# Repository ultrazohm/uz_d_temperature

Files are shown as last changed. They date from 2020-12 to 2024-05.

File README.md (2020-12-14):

# README #

### Ultrazom Temperature Measurement Card ###
This digital sensor card allows the Ultrazohm to measure up to 60 multisensor temperature Channel, of which 40 can be accessed directly on the front panel of the Ultrazohm.
This card is still in development, so please be carefull if you create your own Version of this card!

### Actual Points on the ToDo list ###

* Write some documentation and how-to's
* fix wiring between SPI busses and Connector. Connections made in PCB, buggy in schematic?

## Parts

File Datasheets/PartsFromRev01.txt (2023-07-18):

DC/DC : ROE-2405S 5V 200mA
 https://www.mouser.de/ProductDetail/RECOM-Power/ROE-2405S?qs=wlO1EFRhkBD1PQdCwpEhnw%3D%3D
ADUM : ADUM 4150 ARIZ
https://www.analog.com/en/products/adum4150.html#product-overview

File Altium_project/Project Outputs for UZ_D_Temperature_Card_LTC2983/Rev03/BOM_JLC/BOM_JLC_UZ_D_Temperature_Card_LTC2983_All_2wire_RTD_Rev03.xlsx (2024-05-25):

Comment | Designator | Footprint | LCSC Part Number | Manufacturer Part Number
0.1 µF | C1A, C1B, C1C, C5A, C5B, C5C, C6A, C6B, C6C, C10A, C10B, C10C, C11A, C11B, C11C, C12A, C12B, C12C, C14A, C14B, C14C, C15A, C15B, C15C, C16A, C16B, C16C, C17A, C17B, C17C, C18A, C18B, C18C, C19A, C19B, C19C, C20A, C20B, C20C, C21A, C21B, C21C, C22A, C22B, C22C, C23A, C23B, C23C, C24A, C24B, C24C, C25A, C25B, C25C, C26A, C26B, C26C, C27A, C27B, C27C, C28A, C28B, C28C, C29A, C29B, C29C, C30A, C30B, C30C, C31A, C31B, C31C, C32A, C32B, C32C, C33A, C33B, C33C, C35 | C_0603 | C14663 | C0603X104K5RAC7411
10 µF | C2A, C2B, C2C, C3A, C3B, C3C, C4A, C4B, C4C, C7A, C7B, C7C, C8A, C8B, C8C, C9A, C9B, C9C, C13A, C13B, C13C, C34, C36 | C_0603 | C19702 | GRM185R60J106ME15D
100 nF | C37 | C_0603 | C14663 | C0603C104K9PACTU
150060GS84000 | D1A, D1B, D1C, D2 | WL-SMCW_0603 | C72043 | 150060GS84000
0154.500DR | F1 | Littlefuse_154 | C720204 | 0154.500DR
10k | R1A, R1B, R1C | RES 0603_1608 | C25804 | RK73B1JTTD103J
680R | R2A, R2B, R2C, R69 | RES 0603_1608 | C23228 | RK73B1JTTDD681J
0R | R3A, R3B, R3C, R4A, R4B, R4C, R5A, R5B, R5C, R6A, R6B, R6C, R7A, R7B, R7C, R8A, R8B, R8C, R9A, R9B, R9C, R10A, R10B, R10C, R11A, R11B, R11C, R12A, R12B, R12C, R13A, R13B, R13C, R14A, R14B, R14C, R15A, R15B, R15C, R16A, R16B, R16C, R17A, R17B, R17C, R18A, R18B, R18C, R19A, R19B, R19C, R20A, R20B, R20C, R21A, R21B, R21C, R22A, R22B, R22C, R23A, R23B, R23C, R25A, R25B, R25C, R26A, R26B, R26C, R28A, R28B, R28C, R30A, R30B, R30C, R32A, R32B, R32C, R34A, R34B, R34C, R36A, R36B, R36C, R38A, R38B, R38C, R40A, R40B, R40C, R42A, R42B, R42C, R48, R50, R51, R52, R53, R54, R56, R57, R58, R59, R60, R62, R63, R64, R65, R66, R68, R70 | RES 0603_1608 | C21189 | RC0603JR-070RL
1k | R24A, R24B, R24C | RES 0603_1608 | C21190 | 0603WAF1001T5E
R_TF | R49 | RESC1608X55X30NL15T15 | C21189
4k7 | R71, R72, R73 | RES 0603_1608 | C23162 | 0603WAF4701T5E
100k | R75, R76 | RES 0603_1608 | C25803 | RK73B1JTTD104J
M24C02-WMN6TP | U1 | D0008A_N | C7562 | M24C02-WMN6TP
ADUM4150 | U2A, U2B, U2C | SOIC-20-ADUM4150 | C660948
DC/DC_24_5 | U3A, U3B, U3C | SIP4DCDC | C970824
LTC2983 | U4A, U4B, U4C | 48_LGFP(7x7) | C427448
DC/DC_24_3V3 | U5 | SIP4DCDC | C7500913
IPL1-115-01-L-D-RA-K | X1A, X1C | IPL1-115-01-XX-D-RA | C7423882 | IPL1-115-01-L-D-RA-K

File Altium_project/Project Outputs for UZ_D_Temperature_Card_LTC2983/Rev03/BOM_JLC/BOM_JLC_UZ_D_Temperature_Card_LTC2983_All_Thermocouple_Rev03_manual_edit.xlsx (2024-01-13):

Comment | Designator | Footprint | LCSC Part Number | Alternative
0.1 µF | C1A, C1B, C1C, C5A, C5B, C5C, C6A, C6B, C6C, C10A, C10B, C10C, C11A, C11B, C11C, C12A, C12B, C12C, C14A, C14B, C14C, C15A, C15B, C15C, C16A, C16B, C16C, C17A, C17B, C17C, C18A, C18B, C18C, C19A, C19B, C19C, C20A, C20B, C20C, C21A, C21B, C21C, C22A, C22B, C22C, C23A, C23B, C23C, C24A, C24B, C24C, C25A, C25B, C25C, C26A, C26B, C26C, C27A, C27B, C27C, C28A, C28B, C28C, C29A, C29B, C29C, C30A, C30B, C30C, C31A, C31B, C31C, C32A, C32B, C32C, C33A, C33B, C33C, C35 | C_0603 | C2803384
10 µF | C2A, C2B, C2C, C3A, C3B, C3C, C4A, C4B, C4C, C7A, C7B, C7C, C8A, C8B, C8C, C9A, C9B, C9C, C13A, C13B, C13C, C34, C36 | C_0603 | C5240381
100 nF | C37 | C_0603 | C2803384
150060GS84000 | D1A, D1B, D1C, D2 | WL-SMCW_0603 | C72043
0154.500DR | F1 | Littlefuse_154 | C720204
10k | R1A, R1B, R1C | RES 0603_1608 | C25804
680R | R2A, R2B, R2C, R69 | RES 0603_1608 | C23228
0R | R3A, R3B, R3C, R4A, R4B, R4C, R5A, R5B, R5C, R6A, R6B, R6C, R7A, R7B, R7C, R48, R50, R51, R52, R53, R54, R56, R57, R58, R59, R60, R62, R63, R64, R65, R66, R68, R70 | RES 0603_1608 | C21189
1k | R8A, R8B, R8C, R9A, R9B, R9C, R10A, R10B, R10C, R11A, R11B, R11C, R12A, R12B, R12C, R13A, R13B, R13C, R14A, R14B, R14C, R15A, R15B, R15C, R16A, R16B, R16C, R17A, R17B, R17C, R18A, R18B, R18C, R19A, R19B, R19C, R20A, R20B, R20C, R21A, R21B, R21C, R22A, R22B, R22C, R23A, R23B, R23C | RES 0603_1608 | C21190
R_TF | R49 | RESC1608X55X30NL15T15 | C21189
4k7 | R71, R72, R73 | RES 0603_1608 | C23162
100k | R75, R76 | RES 0603_1608 | C25803
M24C02-WMN6TP | U1 | D0008A_N | C7562
ADUM4150 | U2A, U2B, U2C | SOIC-20-ADUM4150 | C660948
DC/DC_24_5 | U3A, U3B, U3C | SIP4DCDC | C970824
LTC2983ILX | U4A, U4B, U4C | 48_LGFP(7x7) | C427448
DC/DC_24_3V3 | U5 | SIP4DCDC | C7500913 | C2684906
IPL1-115-01-L-D-RA-K | X1A, X1C | IPL1-115-01-XX-D-RA | C7423882

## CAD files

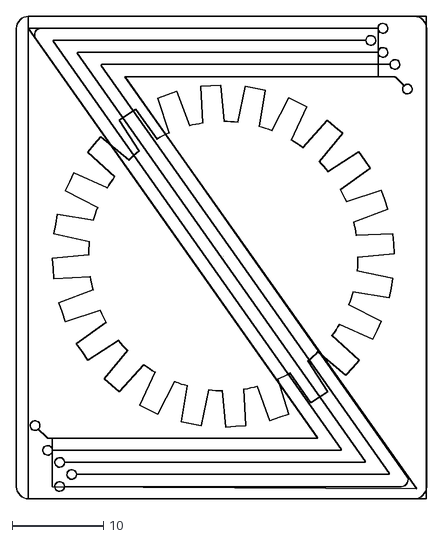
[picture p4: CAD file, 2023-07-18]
logo/V4_fit_mirrored.dxf
45.0 x 52.9

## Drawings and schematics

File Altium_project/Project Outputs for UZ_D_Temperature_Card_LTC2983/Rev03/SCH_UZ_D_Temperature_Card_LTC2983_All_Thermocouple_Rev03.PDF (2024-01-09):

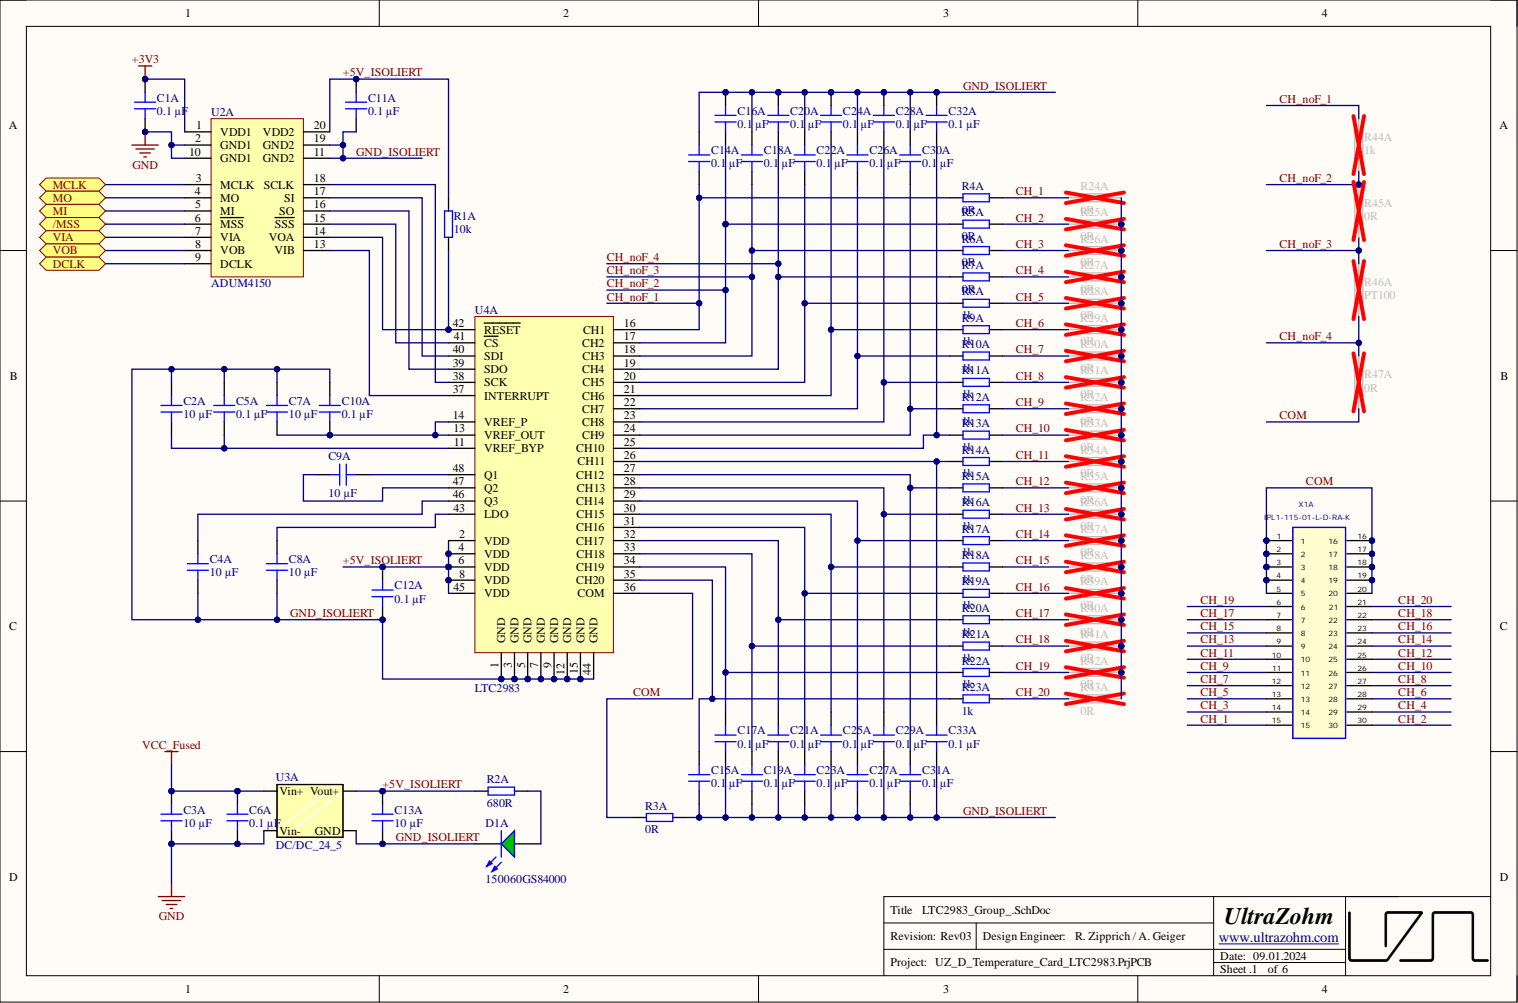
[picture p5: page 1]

1 0 | | 15 SO 16 SI 17 SCLK 18 GND2 19 VDD2 20 4 SSS 1 1

MCL
MI /MSS VIA VOB

1 3

4 | 1 8
3 | 1 9
3 | 2 0

1 3 | | 2 4
1 1 | | 2 5

4 3 | 3 0
2 | 3 1 | 1

G N D _ISO LIE RT

Rev i s n

Dat e :

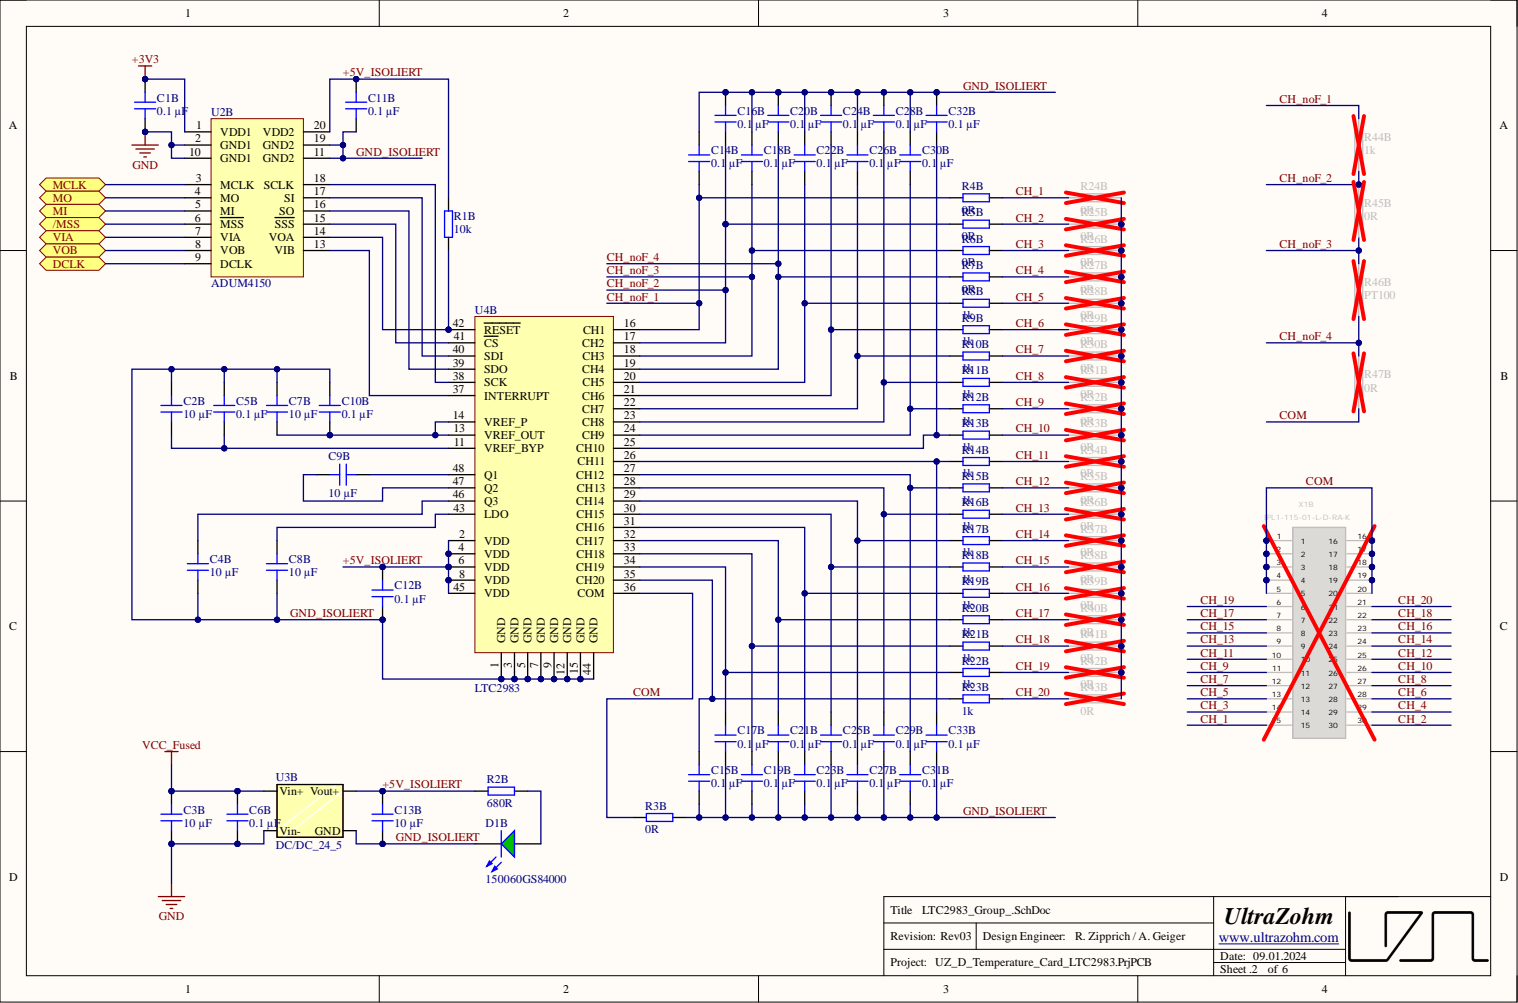
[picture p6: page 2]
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

MCL
MI /MSS VIA VOB

4 | 1 8
3 | 1 9
3 | | 2 0

1 3 | | 2 4
1 1 | | 2 5

4 3 | 3 0
2 | 3 1 | 1

G N D _ISO LIE RT

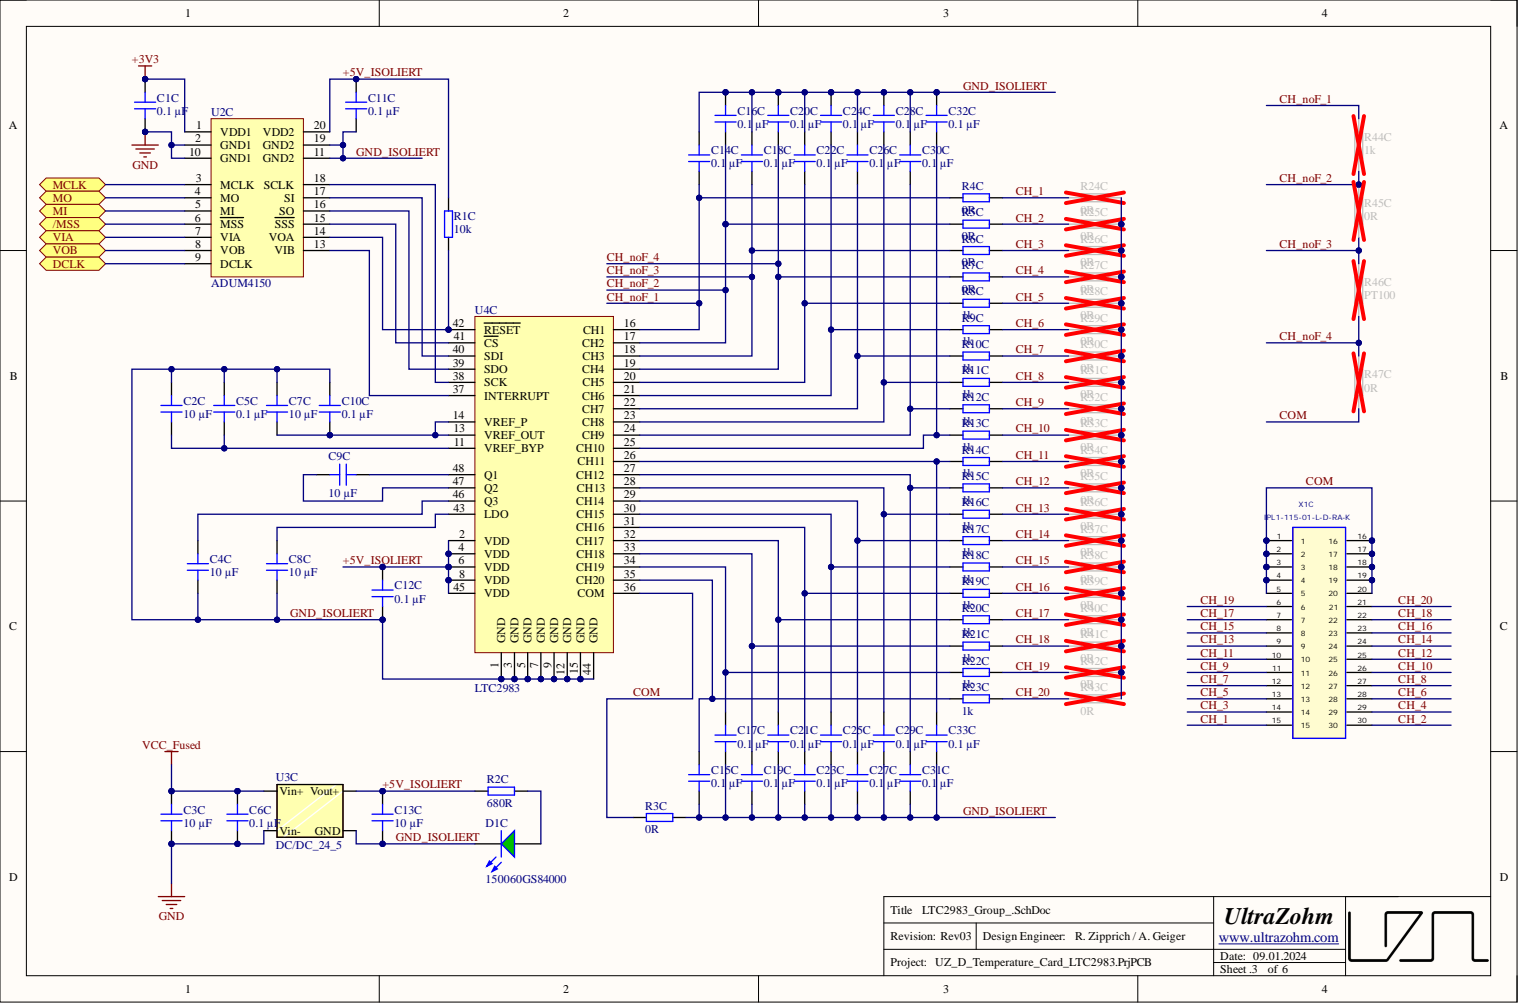
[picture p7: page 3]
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

MCL
MI /MSS VIA VOB

4 | 1 8
3 | 1 9
3 | | 2 0

1 3 | | 2 4
1 1 | | 2 5

4 3 | 3 0
2 | 3 1 | 1

G N D _ISO LIE RT

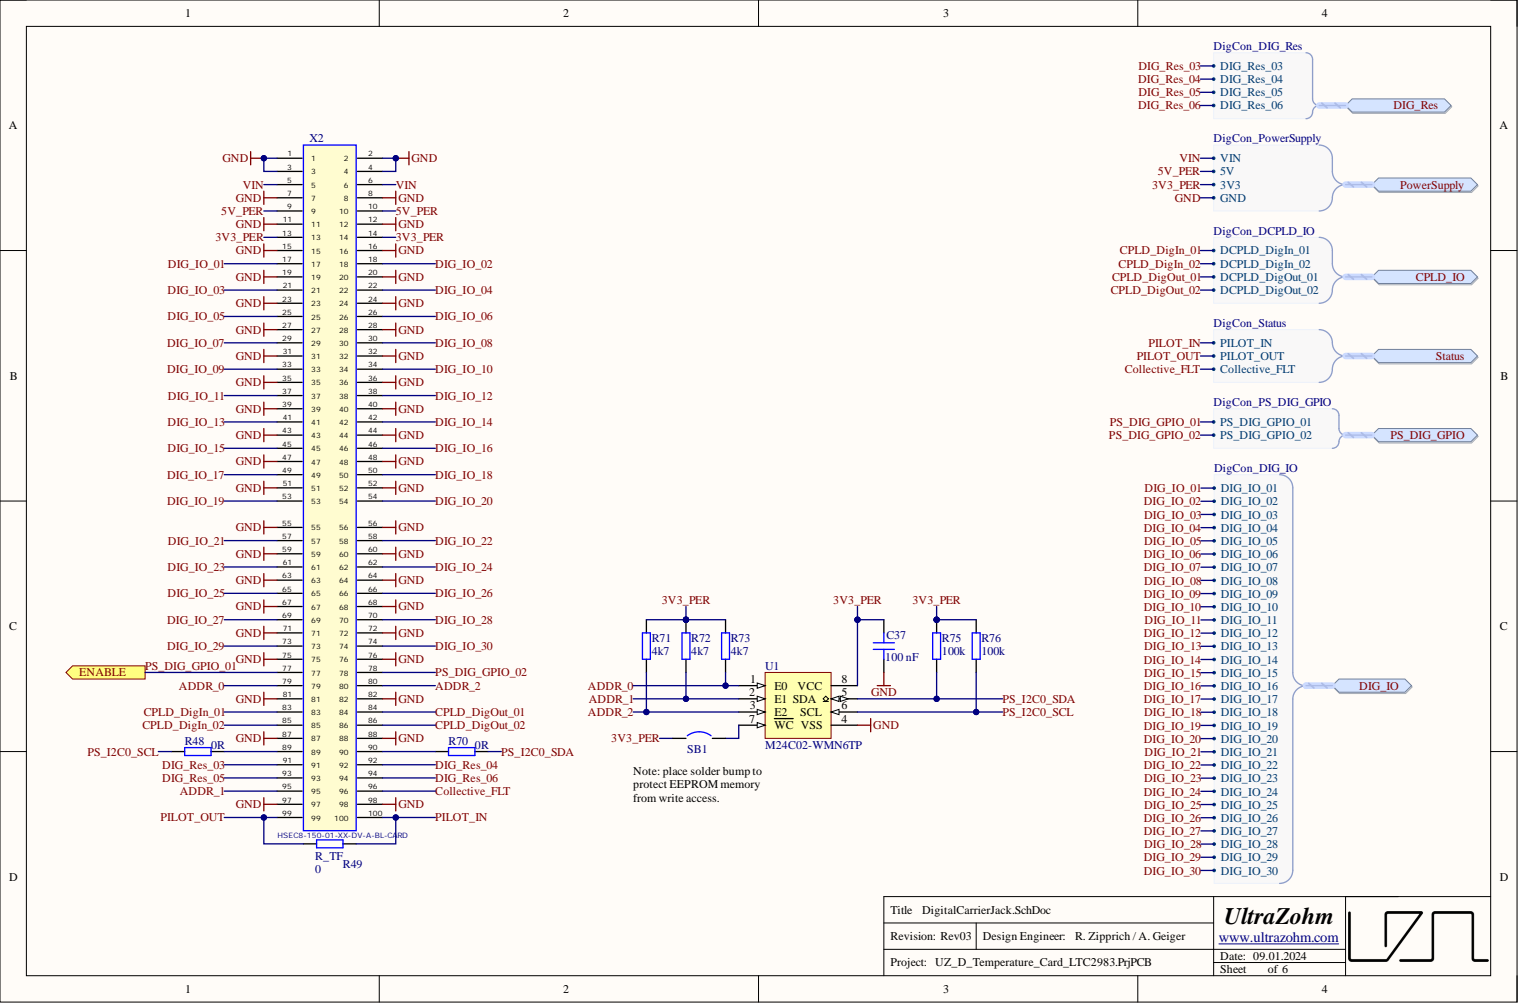
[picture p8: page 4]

Note: place solder bump to
protect EEPROM memory
from write access.

HSEC8-150-01-XX-DV-A-BL-CARD

Revision:

Date: 09.01.2024

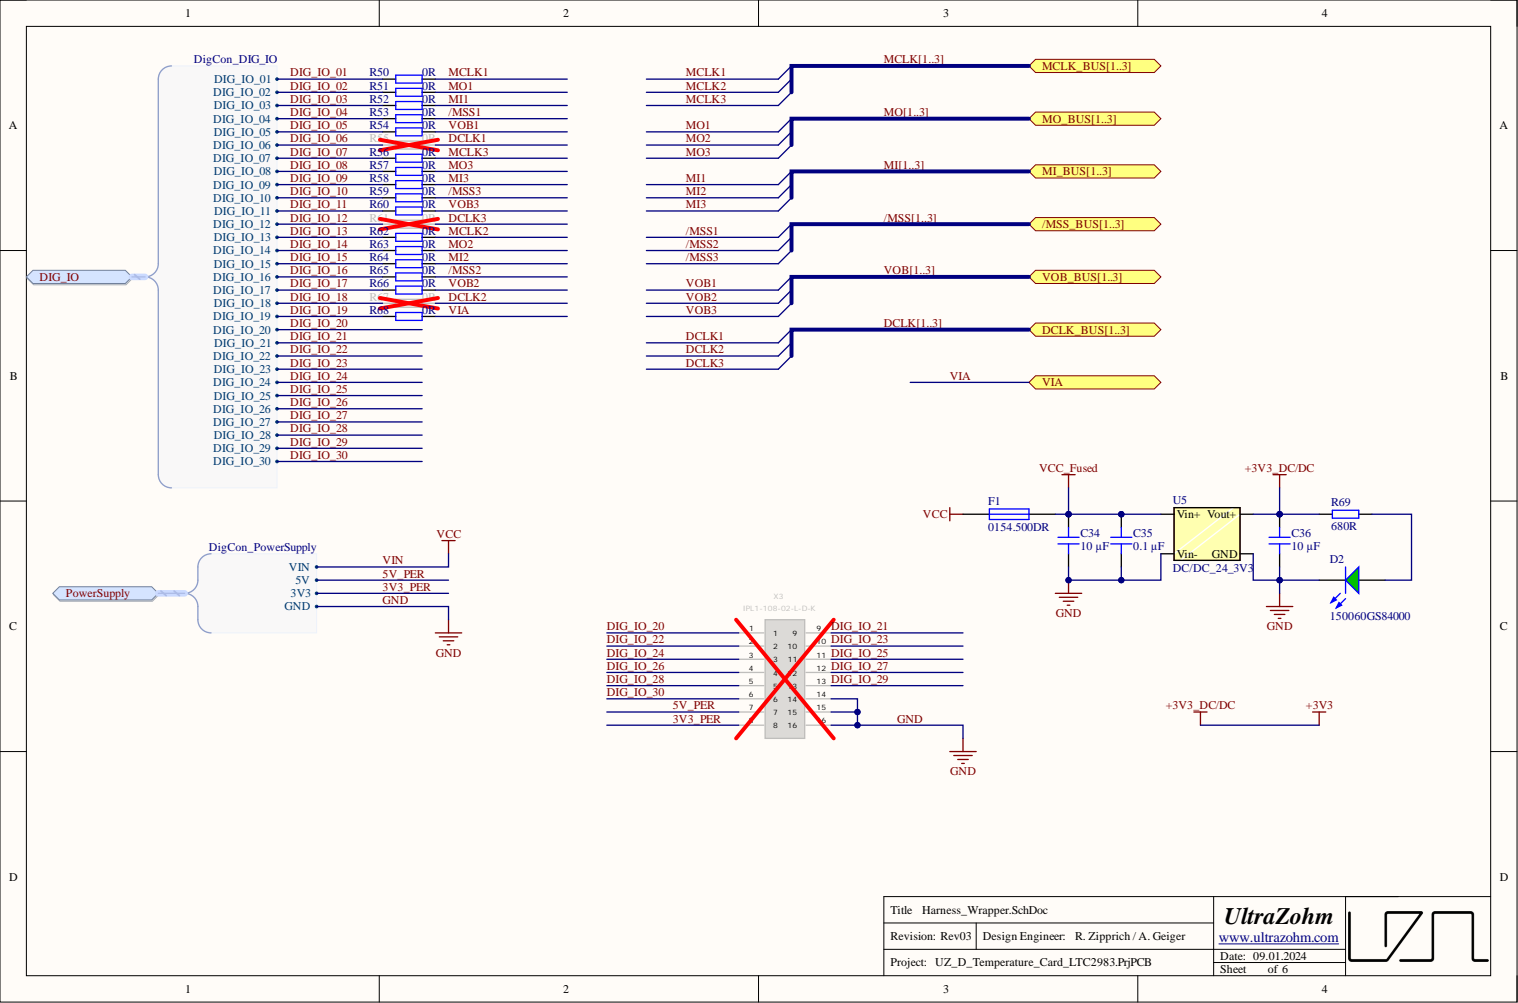
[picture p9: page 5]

1 5
1 6

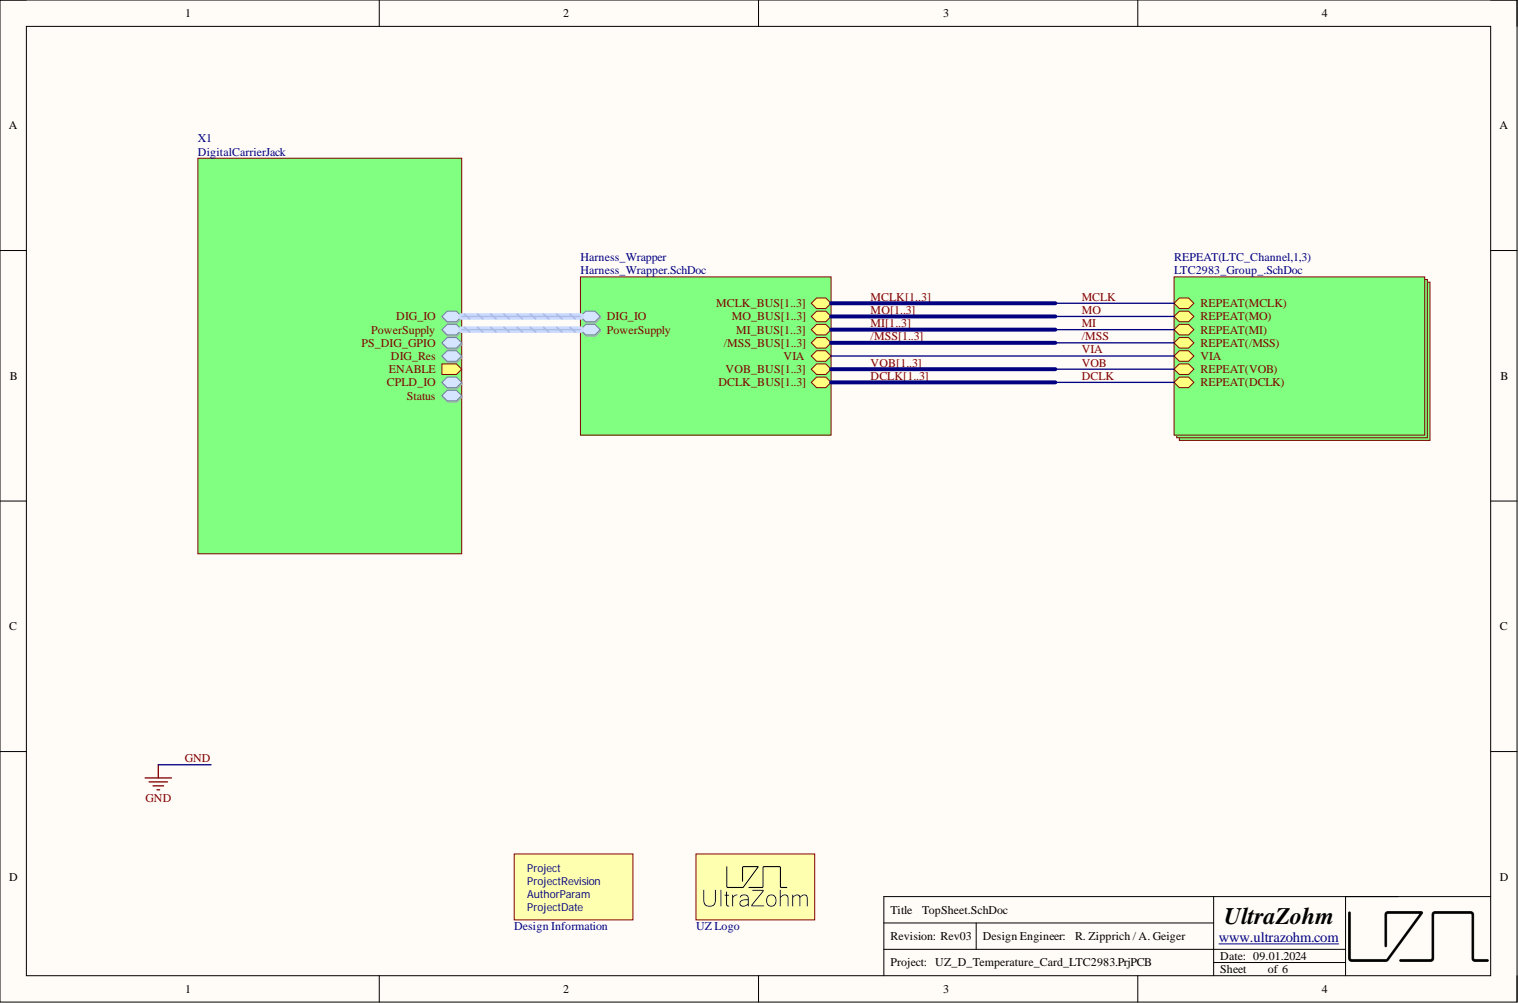
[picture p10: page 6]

Revision:

Date: 09.01.2024

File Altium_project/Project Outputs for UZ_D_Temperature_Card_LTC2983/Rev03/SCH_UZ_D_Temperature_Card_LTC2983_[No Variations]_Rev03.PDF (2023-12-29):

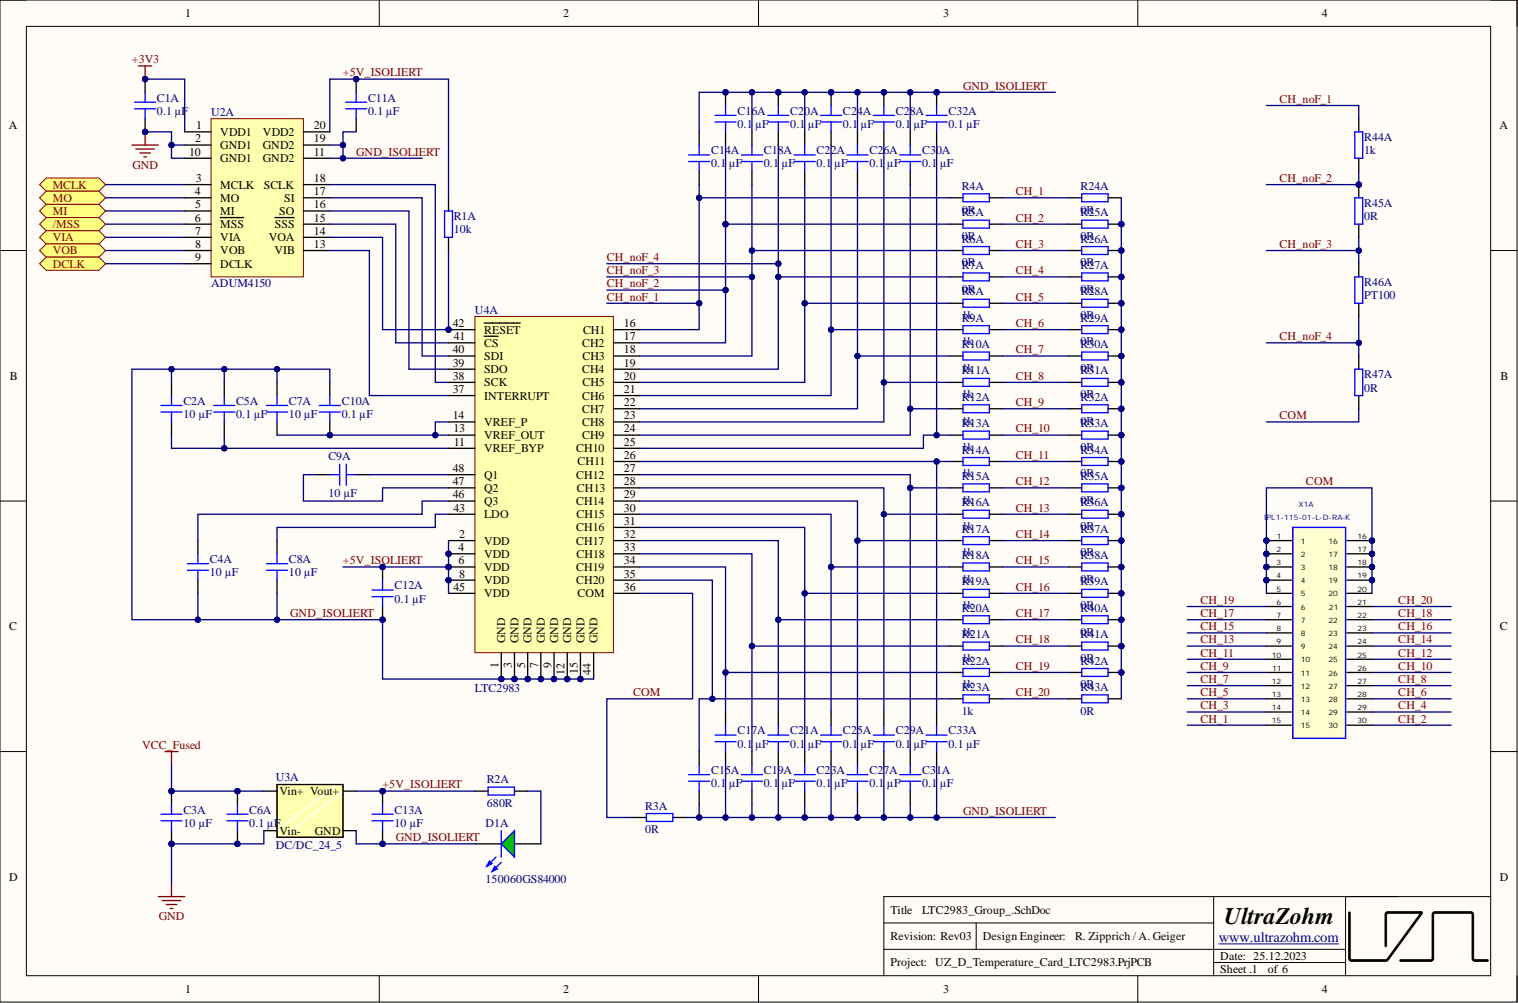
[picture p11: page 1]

1 0 | | 15 SO 16 SI 17 SCLK 18 GND2 19 VDD2 20 4 SSS 1 1

MCL
MI /MSS VIA VOB

1 3

4 | 1 8
3 | 1 9
3 | 2 0

1 3 | | 2 4
1 1 | | 2 5

4 3 | 3 0
2 | 3 1 | 1

G N D _ISO LIE RT

Rev i s n

Dat e :

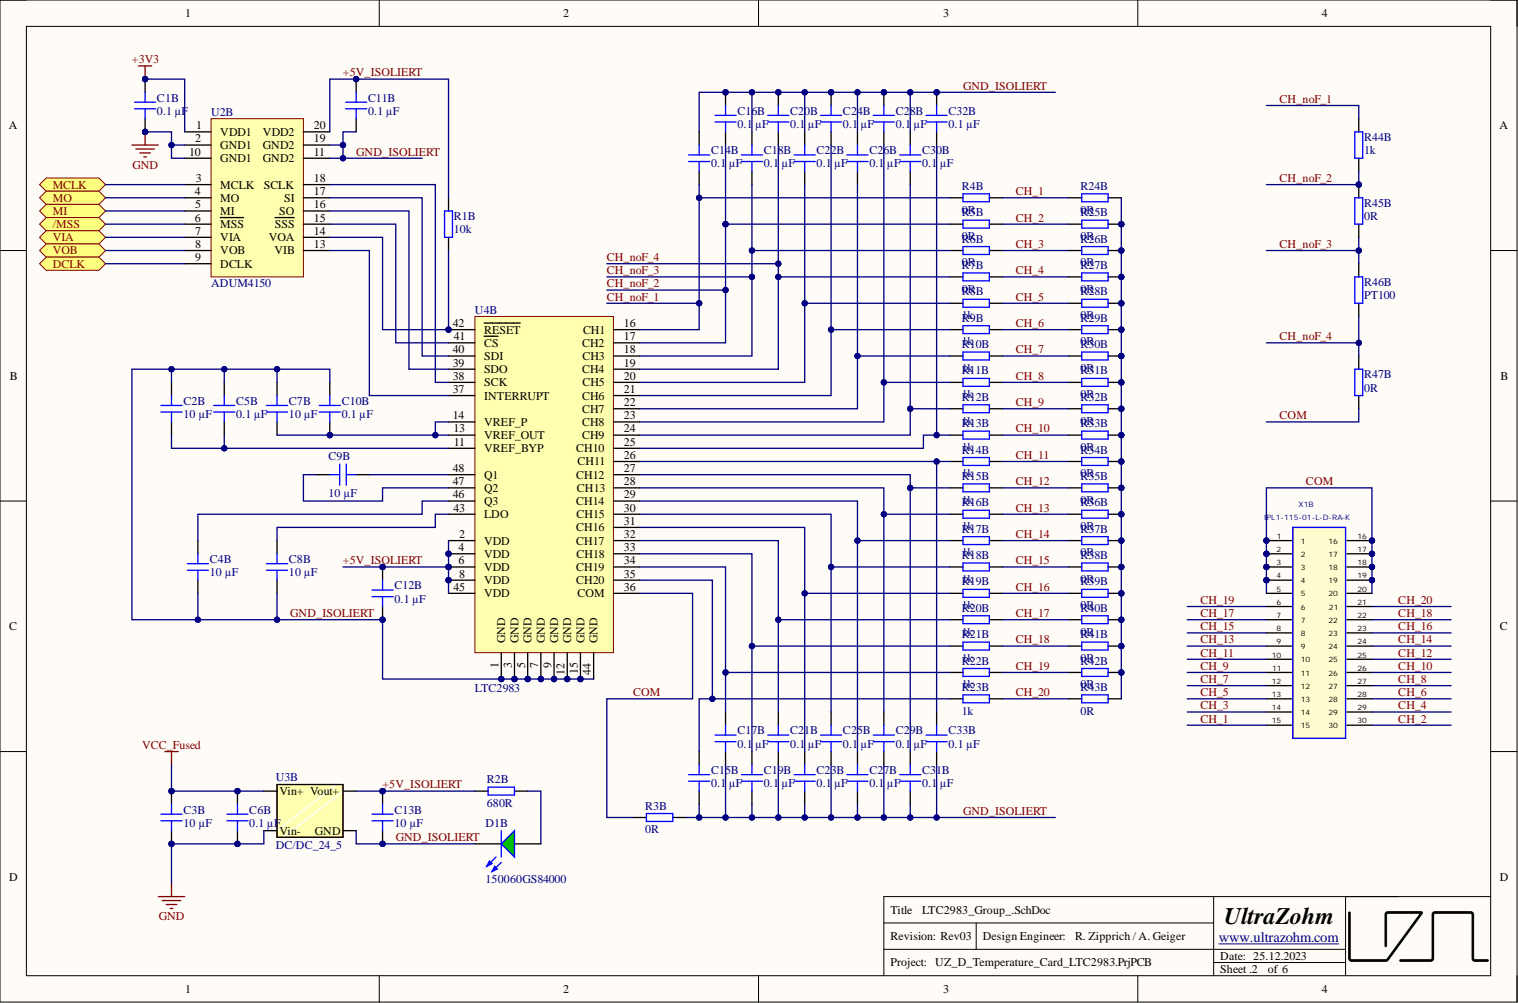
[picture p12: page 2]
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

MCL
MI /MSS VIA VOB

4 | 1 8
3 | 1 9
3 | | 2 0

1 3 | | 2 4
1 1 | | 2 5

4 3 | 3 0
2 | 3 1 | 1

G N D _ISO LIE RT

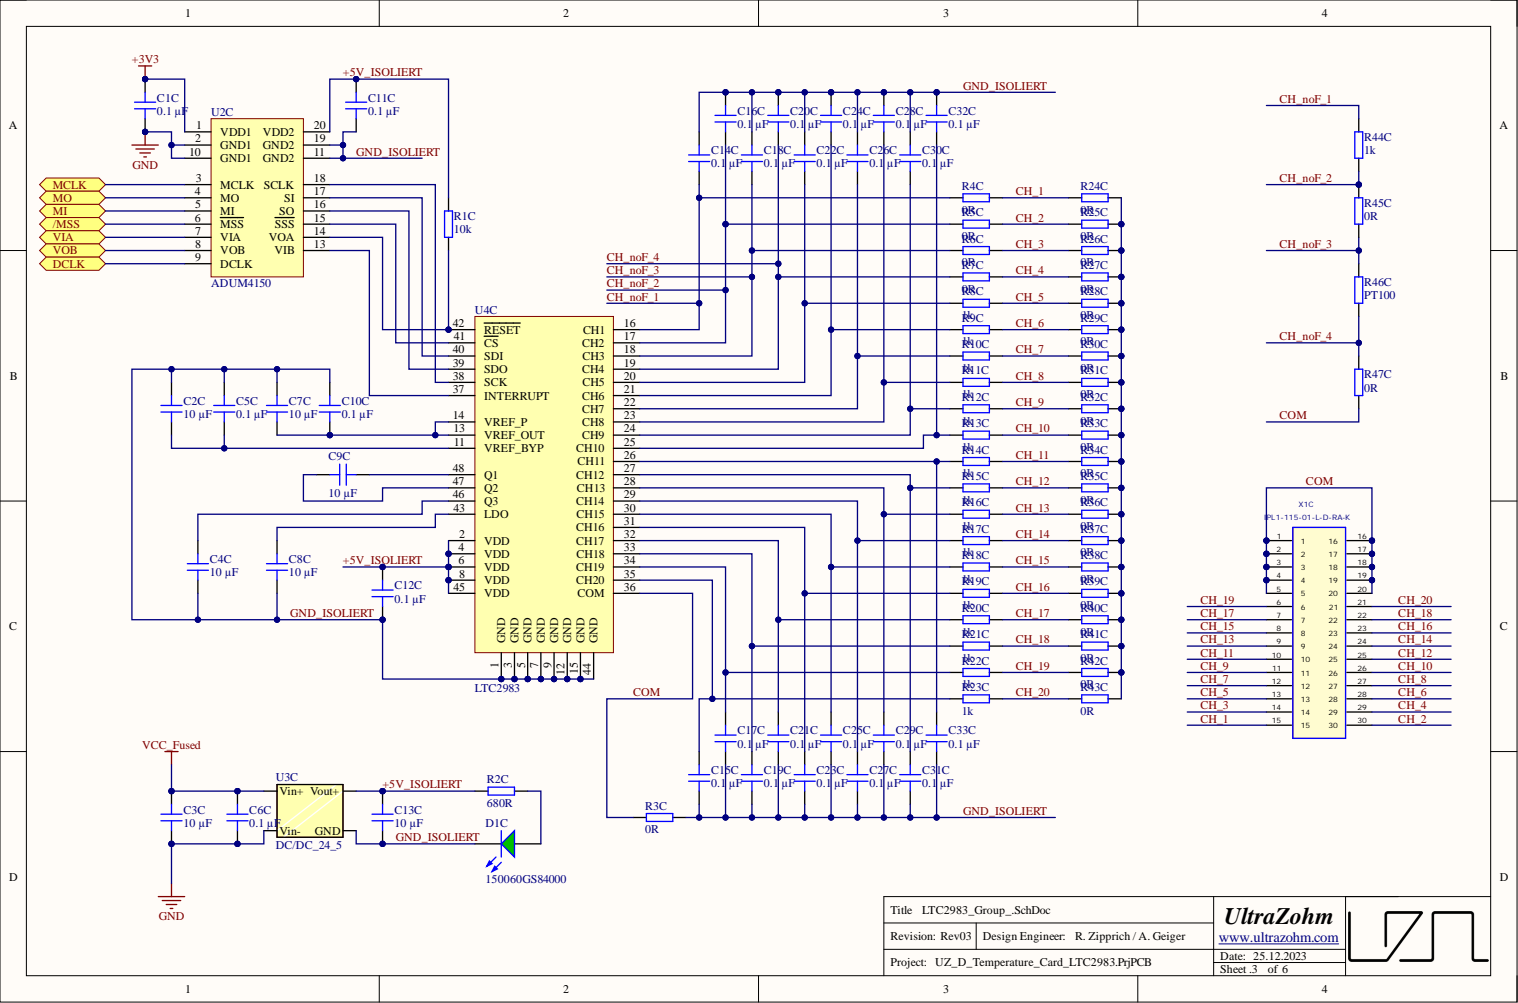
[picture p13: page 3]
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

MCL
MI /MSS VIA VOB

4 | 1 8
3 | 1 9
3 | | 2 0

1 3 | | 2 4
1 1 | | 2 5

4 3 | 3 0
2 | 3 1 | 1

G N D _ISO LIE RT

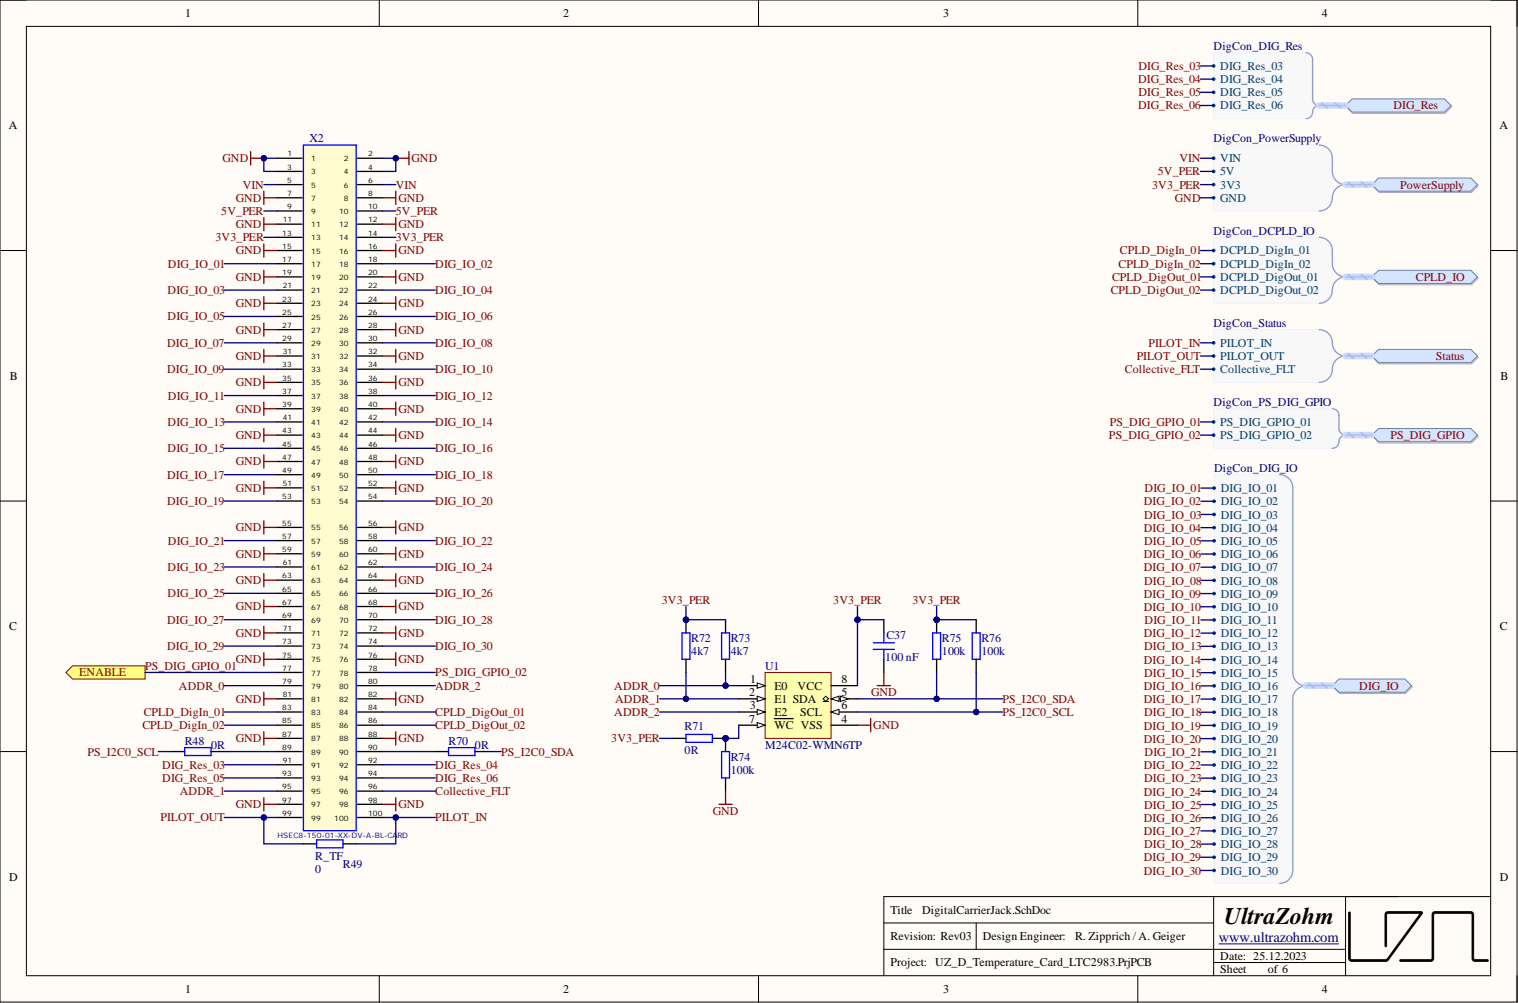
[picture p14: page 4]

HSEC8-150-01-XX-DV-A-BL-CARD

Revision:

Date: 25.12.2023

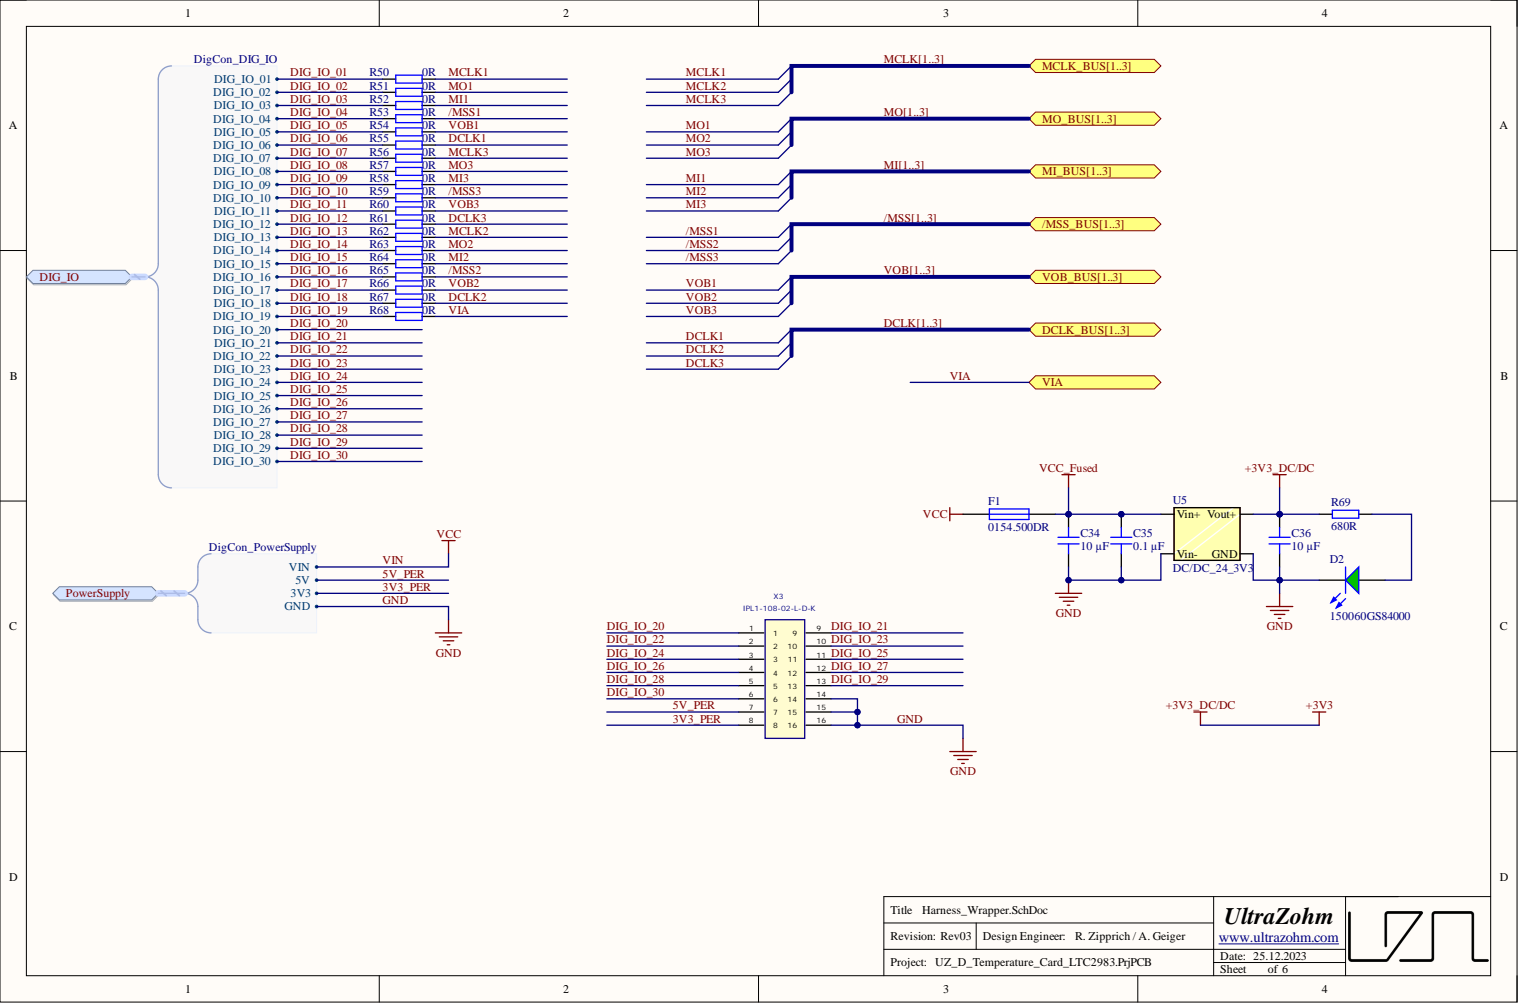
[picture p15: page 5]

1 5
1 6

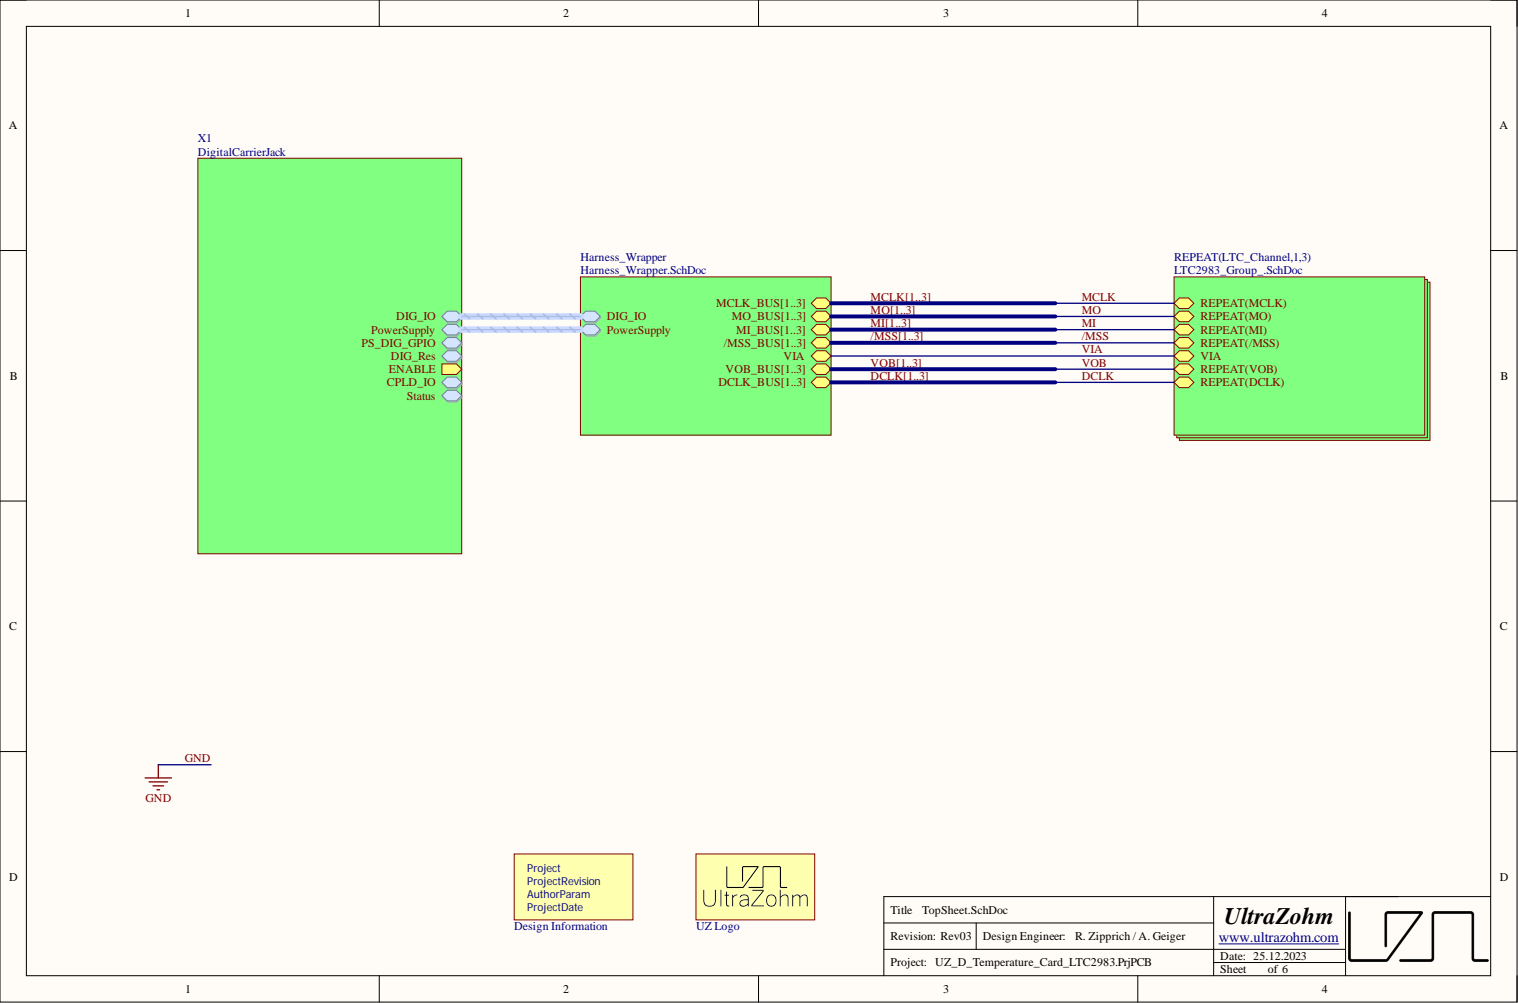
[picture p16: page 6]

Revision:

Date: 25.12.2023

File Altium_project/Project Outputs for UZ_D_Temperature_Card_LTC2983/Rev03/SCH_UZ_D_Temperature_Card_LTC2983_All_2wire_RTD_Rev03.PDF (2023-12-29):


1 0 | | 15 SO 16 SI 17 SCLK 18 GND2 19 VDD2 20 4 SSS 1 1

MCL
MI /MSS VIA VOB

1 3

4 | 1 8
3 | 1 9
3 | 2 0

1 3 | | 2 4
1 1 | | 2 5

4 3 | 3 0
2 | 3 1 | 0

G N D _ISO LIE RT

Rev i s n

Dat e :

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

MCL
MI /MSS VIA VOB

4 | 1 8
3 | 1 9
3 | | 2 0

1 3 | | 2 4
1 1 | | 2 5

4 3 | 3 0
2 | 3 1 | 0

G N D _ISO LIE RT

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

MCL
MI /MSS VIA VOB

4 | 1 8
3 | 1 9
3 | | 2 0

1 3 | | 2 4
1 1 | | 2 5

4 3 | 3 0
2 | 3 1 | 0

G N D _ISO LIE RT


HSEC8-150-01-XX-DV-A-BL-CARD

Revision:

Date: 29.12.2023


1 5
1 6


Revision:

Date: 29.12.2023







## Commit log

2020-12-10 Iniitial commit for the Temperature Measurement Card
    [DigitalCarrierJack.SchDoc, Harness_Wrapper.SchDoc, LTC2983_Group_.SchDoc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]
2020-12-10 Rearrange the repository and edit the Readme
    [DigitalCarrierJack.SchDoc, Harness_Wrapper.SchDoc, LTC2983_Group_.SchDoc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]
2020-12-14 Readme angepasst Logos und Versionsnummer auf dem PCB hinzugefügt
    [UZ_D_Temperature_Card_LTC2983.PrjPCB]
2021-02-11 - Switched to Ultrazohm Altium Library - fixed some issues discussed in the bitbucket - probably issue with the library and resistors? - need to reroute the whole PCB
    [DigitalCarrierJack.SchDoc, Harness_Wrapper.SchDoc, LTC2983_Group_.SchDoc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]
2021-03-04 Projekt reworked: - switched to UZ-Altium-Lib (#2) - replace decouple C (#7) - add some labels for the channels (#3) / more informations will be written on the back - use netlabels (#5) - 2-Layer PCB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
    open points and issues:
    - need more doku on the back
    - add ip-core to the sw_repo
    - fix bus-connectivity in the harness-wrapper sheet (some connections are missing)
    - another review by eyke ;)
    [DigitalCarrierJack.SchDoc, Harness_Wrapper.SchDoc, LTC2983_Group_.SchDoc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]
2021-03-05 changed the connector to the UZ-Lib
    [Harness_Wrapper.SchDoc, LTC2983_Group_.SchDoc, TopSheet.SchDoc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]
2021-03-06 - removed via-in-pad - add power-supply-selector (own DC/DC or 5V from UZ-Carrier) - add connector for spare IO - add connector for I2C
    STILL PROBLEM WITH THE CONNNECTIVITY IN MULTI_CHANNEL_DESIGN!!! GNARF
    [DigitalCarrierJack.SchDoc, Harness_Wrapper.SchDoc, LTC2983_Group_.SchDoc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]
2021-03-08 - add some description - made "connectivity" through DRC-violation...
    [TopSheet.SchDoc, UZ_D_Temperature_Card_LTC2983.PrjPCB]
2021-03-10 - fixed connectivity issue with the multichannel-design - fixed some warnings and waved unrouted net violations (GND-Pins within the edge-card-connector, they will be connected when the card is plugg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
    [Harness_Wrapper.SchDoc, LTC2983_Group_.SchDoc, TopSheet.SchDoc]
2021-03-11 - radius the front corners of the PCB - generate gerberfiles
    [UZ_D_Temperature_Card_LTC2983.PrjPCB]
2021-05-12 PCB-Lib auf neusten Stand geupdated
    [Harness_Wrapper.SchDoc, LTC2983_Group_.SchDoc]
2021-05-17 Initial commit for development-branch
    [UZ_D_Temperature_Card_LTC2983.GBL, UZ_D_Temperature_Card_LTC2983.GBO, UZ_D_Temperature_Card_LTC2983.GBP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]
2021-05-18 push more data do develop, something went wrong with the initial commit
    [DigitalCarrierJack.SchDoc, Harness_Wrapper.SchDoc, LTC2983_Group_.SchDoc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]
2021-05-18 Bugfix: UZ-Side of the Adum-Isolator was powered with 5V, changed to the needed Voltage of 3V3.
    [Harness_Wrapper.SchDoc, LTC2983_Group_.SchDoc, UZ_D_Temperature_Card_LTC2983.PrjPCB]
2021-05-18 update master to merge
    [Harness_Wrapper.SchDoc, LTC2983_Group_.SchDoc, UZ_D_Temperature_Card_LTC2983.PrjPCB]
2021-05-26 Change Template to Template_uni_kassel
    [DigitalCarrierJack.SchDoc, Harness_Wrapper.SchDoc, LTC2983_Group_.SchDoc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]
2023-06-20 initial commit including first changes
    [DigitalCarrierJack.SchDoc, Harness_Wrapper.SchDoc, LTC2983_Group_.SchDoc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]
2023-07-02 updated variant
    [DigitalCarrierJack.SchDoc, Harness_Wrapper.SchDoc, LTC2983_Group_.SchDoc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]
2023-07-03 updated variant since CH1-4 must not be connected to Samtec Connector anymore
    [UZ_D_Temperature_Card_LTC2983.PrjPCB]
2023-07-03 Shifted samtec connector inside of UZ 2mm moreinto the pcb to avoid collision with mounting rails
2023-07-08 set Samtec IPL of "inner" channel to not fitted
    [UZ_D_Temperature_Card_LTC2983.PrjPCB]
2023-07-17 final changes, generated outputs Rev02 for JLCPCB
    [Harness_Wrapper.SchDoc, LTC2983_Group_.SchDoc, UZ_D_Temperature_Card_LTC2983.PrjPCB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]
2023-07-18 added production files for Rev02
    [BOM_JLC_UZ_D_Temperature_Card_LTC2983_All_Thermocouple_Rev02.xlsx, BOM_JLC_UZ_D_Temperature_Card_LTC2983_All_Thermocouple_Rev02_w_JLC_part_numbers.xlsx, Pick_a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]
2023-08-08 Changes according to issue
    [DigitalCarrierJack.SchDoc, Harness_Wrapper.SchDoc, LTC2983_Group_.SchDoc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]
2023-08-08 uncommited changes to the project file
    [UZ_D_Temperature_Card_LTC2983.PrjPCB]
2023-09-13 corrected some mistakes in the assembly variant all thermocouple, corrected naming convention for channelgroups on the pcb
    [LTC2983_Group_.SchDoc, UZ_D_Temperature_Card_LTC2983.PrjPCB]
2023-09-14 added variant for 9 2wire RTD measurement (PT100/PT1000)
    [Harness_Wrapper.SchDoc, LTC2983_Group_.SchDoc, UZ_D_Temperature_Card_LTC2983.PrjPCB]
2023-12-24 add EEPROM
    [DigitalCarrierJack.SchDoc]
2023-12-25 annotate; change chip designator from IC* to U*
    [DigitalCarrierJack.SchDoc, Harness_Wrapper.SchDoc, LTC2983_Group_.SchDoc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]
2023-12-25 transfer changes to PCB
    [DigitalCarrierJack.SchDoc]
2023-12-25 remove I2C connector
    [DigitalCarrierJack.SchDoc, Harness_Wrapper.SchDoc, TopSheet.SchDoc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]
2023-12-25 schematic update of EEPROM reference to UZ Altium lib
    [DigitalCarrierJack.SchDoc, UZ_D_Temperature_Card_LTC2983.PrjPCB]
2023-12-27 streamlined assembly variants -> (not placing protect pin resistors of EEPROM was only respected in 2-wire RTD variant, did this also for TypeK variant)
    [DigitalCarrierJack.SchDoc, UZ_D_Temperature_Card_LTC2983.PrjPCB]
2023-12-29 generate production files for Rev02
    [BOM_JLC_UZ_D_Temperature_Card_LTC2983_All_Thermocouple_Rev03.xlsx, Pick_and_Place_UZ_D_Temperature_Card_LTC2983_All_Thermocouple_Rev03.csv, UZ_D_Temperature_Ca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]
2023-12-29 added LCSC part numbers to JLC_BOM
    [BOM_JLC_UZ_D_Temperature_Card_LTC2983_All_Thermocouple_Rev03.xlsx]
2024-01-02 maße minimal angepasst, runde ecken waren leicht verschoben
    gerber files neu generiert und die alten gelöscht.
    jlc nummern angepasst
    [BOM_JLC_UZ_D_Temperature_Card_LTC2983_All_Thermocouple_Rev03.xlsx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]
2024-01-09 add solder bumper instead of pull-up at EEPROM write access protection pin
    [BOM_JLC_UZ_D_Temperature_Card_LTC2983_All_Thermocouple_Rev03.xlsx, DigitalCarrierJack.SchDoc, Pick_and_Place_UZ_D_Temperature_Card_LTC2983_All_Thermocouple_Rev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]
2024-01-13 finales update on bom LCSC nummern
    [BOM_JLC_UZ_D_Temperature_Card_LTC2983_All_Thermocouple_Rev03_manual_edit.xlsx]
2024-01-25 update lcsc nummern in lib und schematic
    [DigitalCarrierJack.SchDoc, Harness_Wrapper.SchDoc, LTC2983_Group_.SchDoc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]
2024-05-25 create BoM and PP files for FR (to verify)
    [BOM_JLC_UZ_D_Temperature_Card_LTC2983_All_2wire_RTD_Rev03.xlsx, Pick_and_Place_UZ_D_Temperature_Card_LTC2983_All_2wire_RTD_Rev03.csv]
2026-03-09 shift designator and value of channel resistors next to symbol that they do not overlap and become illegible
    [LTC2983_Group_.SchDoc, UZ_D_Temperature_Card_LTC2983.PrjPCB]
